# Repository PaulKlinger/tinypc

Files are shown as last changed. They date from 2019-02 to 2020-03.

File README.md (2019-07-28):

# TinyPC / ThinkTiny

This repository contains the code, 3d models, and PCB files for my tiny gaming pc and tiny thinkpad. Both projects use the same code.

| | |
|---| ---|
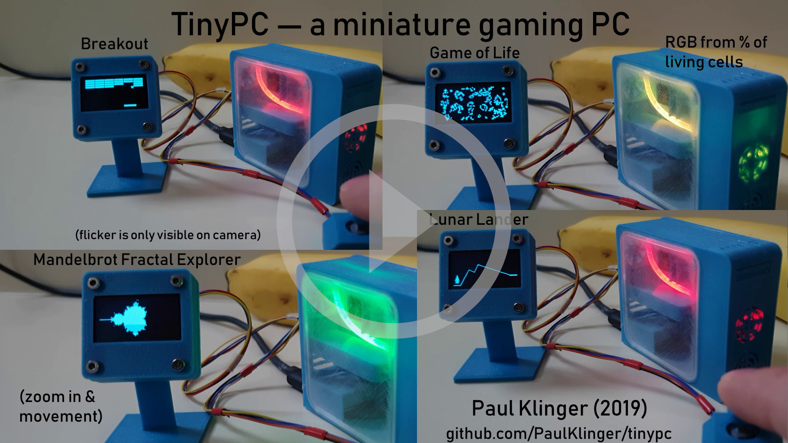
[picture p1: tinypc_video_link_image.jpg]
(https://youtu.be/rgKiFqHrE0A "TinyPC video")
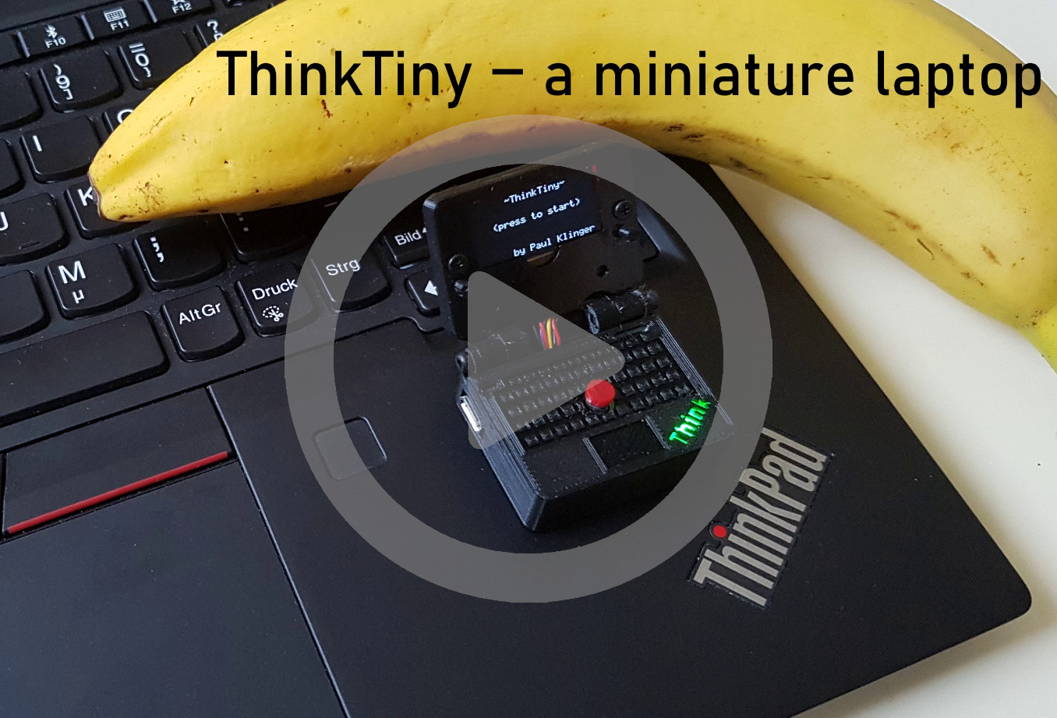
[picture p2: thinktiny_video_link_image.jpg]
(https://youtu.be/0wcxMr_ZupM "ThinkTiny video")
|  |  |

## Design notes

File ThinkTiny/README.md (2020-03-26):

# ThinkTiny — A miniature laptop

(https://youtu.be/0wcxMr_ZupM "Project video")

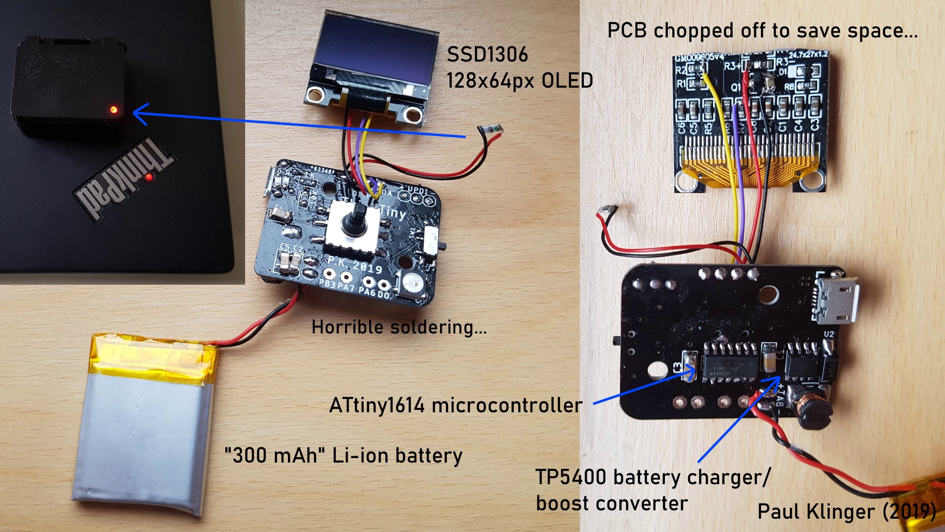
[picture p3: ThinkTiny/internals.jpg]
internals


Components:
- [ATtiny1614 microcontroller](https://octopart.com/attiny1614-ssfr-microchip-82181131)
- [128x64 OLED screen with SSD1306 driver](https://www.aliexpress.com/item/Free-Shipping-White-Blue-Whiteand-Blue-color-0-96-inch-128X64-OLED-Display-Module-For-arduino/32713614136.html)
- [5 way switch](https://www.aliexpress.com/item/32807613480.html)
- [WS2812B LED](https://www.aliexpress.com/item/100pcs-DC5V-WS2812B-4Pins-5050-SMD-with-Built-in-WS2811-IC-Individually-Addressable-Digital-RGB-LED/32542036874.html)
- [2mm PMMA optic fiber](https://www.aliexpress.com/item/5mX-Transparent-side-glow-plastic-PMMA-fiber-optic-cable-solid-core-optic-cable-diameter-2mm-3mm/32807597828.html)
- [power switch](https://www.aliexpress.com/item/32967873133.html)
- [TP5400 charge controller/boost converter](https://www.aliexpress.com/item/32869425291.html)
- [10uH CD54 inductor](https://www.aliexpress.com/item/32956022325.html)
- [Li-ion battery](https://www.aliexpress.com/item/32954488360.html)
- [SS24 diode](https://www.aliexpress.com/item/32904408053.html)
- [10K/6.8K/1K 0805 resistor](https://www.aliexpress.com/item/32880368264.html)
- [5x 47uf 1206 capacitors](https://www.aliexpress.com/item/32373728015.html)
- [2xred 1xgreen 0805 led](https://www.aliexpress.com/item/32816842323.html)
- [Some 30 AWG wire wire](https://www.aliexpress.com/item/30-AWG-Wrapping-Wire-0-25mm-Tin-Plated-Copper-8-Colored-Wire-Wrap-Insulation-Test-Cable/32907507087.html)

I cut off the top of the OLED PCB with flush cutters to make it fit into the case. That's where the pin header sits, so I needed to tap into the connections somewhere else on the PCB. I've marked the points in [this image](black_oled_pin_connection_points.jpg), but be careful, there might be versions of this display with different layout. I also added a capacitor after the voltage regulator on the display board (the three pin component). This gets rid of flickering when there's a lot of white on the screen.

To fit the knob on the 5-way switch the stem needs to be cut off just after the thick section at the top. The knob fits pretty well, but to make sure it doesn't come off I used a drop of superglue to fix it in place. Make sure to turn it upside down while glueing, otherwise the glue runs down into the switch and it stops working...

There's a small piece of fiberoptic in the hole in the display back cover, which transmits and diffuses the light from the red LED. That 0805 LED is directly soldered to an 0805 6.8k resistor and connected back to the main PCB.

The plastic pieces are all printed in PLA with a 0.25mm nozzle and 0.1mm layer height on my [Prusa MK3s](https://shop.prusa3d.com/en/3d-printers/180-original-prusa-i3-mk3-kit.html#). No supports are needed, all the pieces have a flat side to put down on the bed. STL files and the Fusion 360 source file (in case anyone wants to edit them) are in the "3d models" directory. The pcb cover ("pcb cover.stl") is printed with a color change: black filament at the bottom (the top when assembled) and then transparent filament to create the diffuser for the "think" logo and the charging indicator LEDs. I raised the first layer height slightly when printing the pcb cover, so that the keys and "think" font wouldn't get squished together.

The hole on the top right of the pcb cover is used to reprogram the MCU without disassembling everything. I use a small jig with three spring loaded pogo pins ([bought here](https://www.aliexpress.com/item/50pcs-set-New-P75-B1-Dia-1-02mm-100g-Cusp-Spear-Spring-Loaded-Test-Probes-Pogo/32767984398.html)) to connect to three pads (for power, ground, and UPDI data) on the PCB underneath (you need to put some solder in the three holes to make a surface for the pins to push against). The holes are the standard pin header ones, 0.1 inch apart, so you can just solder the pogo pins into three adjacent holes of another protoboard to make a jig. Here's [a picture](https://raw.githubusercontent.com/PaulKlinger/ndice/master/programming_jig.jpg) of the programming jig with a PICkit 4 connected (the PICkit doesn't provide power, so that comes from the usb).

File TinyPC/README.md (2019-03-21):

# TinyPC — A miniature gaming PC

(https://youtu.be/rgKiFqHrE0A "Project video")

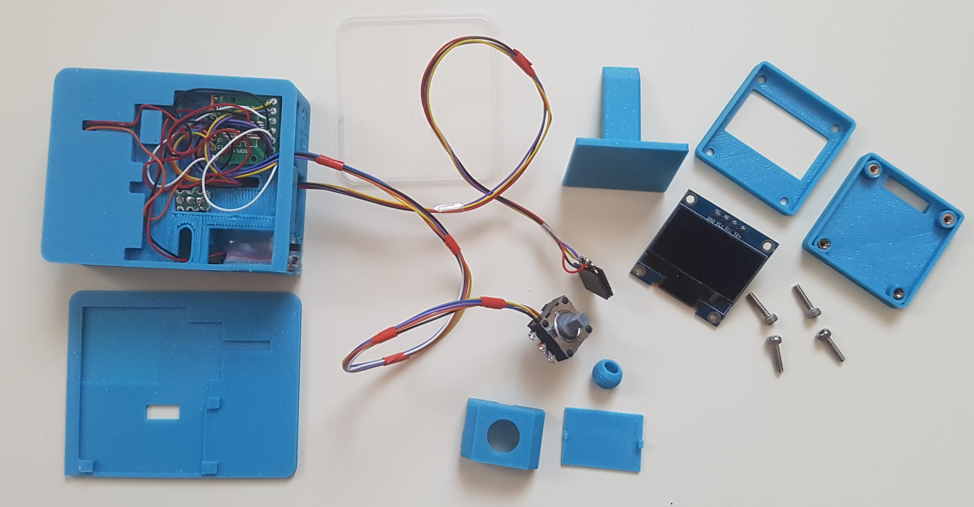
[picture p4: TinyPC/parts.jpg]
parts


Components:
- [ATtiny1614 microcontroller](https://octopart.com/attiny1614-ssfr-microchip-82181131)
- [SOP14 adapter board](https://www.aliexpress.com/item/7kinds-PCB-Board-SOP8-SOP14-SOP16-SOP20-SOP24-SOP28-QFP-FQFP-TQFP-Turn-To-DIP-Adapter/32863813062.html)
- [128x64 OLED screen with SSD1306 driver](https://www.aliexpress.com/item/Free-Shipping-White-Blue-Whiteand-Blue-color-0-96-inch-128X64-OLED-Display-Module-For-arduino/32713614136.html)
- [JS5208 5 way switch](https://octopart.com/js5208-e-switch-7055822?r=sp&s=BNJOYOgrTFqksTVikSivoQ)
- [WS2812B LED](https://www.aliexpress.com/item/100pcs-DC5V-WS2812B-4Pins-5050-SMD-with-Built-in-WS2811-IC-Individually-Addressable-Digital-RGB-LED/32542036874.html)
- [2mm PMMA optic fiber](https://www.aliexpress.com/item/5mX-Transparent-side-glow-plastic-PMMA-fiber-optic-cable-solid-core-optic-cable-diameter-2mm-3mm/32807597828.html)
- micro usb breakout (I used part of a custom PCB from [an earlier project](https://github.com/PaulKlinger/satellite_tracker), you could use [this one](https://www.aliexpress.com/item/10PCS-CJMCU-Breakout-Power-Supply-Module-Micro-USB-Interface-Power-Adapter-Board-USB-5V-Breakout-Module/32815913372.html) for example. Unfortunately all the breakouts I can find use connectors without through hole pins, so they tear out easily.)
- power switch ([this one looks similar to mine](https://www.aliexpress.com/item/Promotion-50-Pcs-SS12D00G3-2-Position-SPDT-1P2T-3-Pin-PCB-Panel-Mini-Vertical-Slide-Switch/32649542037.html))
- [Threaded inserts for the LCD case back](https://www.aliexpress.com/item/100pcs-lot-Brass-insert-M2-M2-5-M3-Through-thread-brass-insert-nut-knurled-nuts/32840519444.html) (These are pretty unnecesary, you can just screw directly into the plastic if you make the hole smaller, or glue the case together. I have a lot of them so I use them for everything. They push into the plastic with a soldering iron set to low heat (~100 °C).)
- [Some 30 AWG wire wire](https://www.aliexpress.com/item/30-AWG-Wrapping-Wire-0-25mm-Tin-Plated-Copper-8-Colored-Wire-Wrap-Insulation-Test-Cable/32907507087.html) to connect everything together.

There's a schematic available [here](schematic/schematic.pdf).

The hole in the side cover (opposite the window) is used to reprogram the MCU without dissasembling the tinypc. I use a small jig with three spring loaded pogo pins ([bought here](https://www.aliexpress.com/item/50pcs-set-New-P75-B1-Dia-1-02mm-100g-Cusp-Spear-Spring-Loaded-Test-Probes-Pogo/32767984398.html)) to connect to three pads (for power, ground, and UPDI data) in a piece of protoboard underneath (you need to put some solder in the three holes to make a surface for the pins to push against). The holes are the standard pin header ones, 0.1 inch apart, so you can just solder the pogo pins into three adjacent holes of another protoboard to make a jig. Here's [a picture](https://raw.githubusercontent.com/PaulKlinger/ndice/master/programming_jig.jpg) of the programming jig with a PICkit 4 connected (the PICkit doesn't provide power, so that comes from the usb). (I don't really recommend the pickit, the AVR support is still in beta and there are some irritating bugs.)

The window is printed using transparent PLA filament. To get it even this transparent I had to polish it a lot, using abrasive paper from 200 to 5000 grit and acrylic polishing compound.

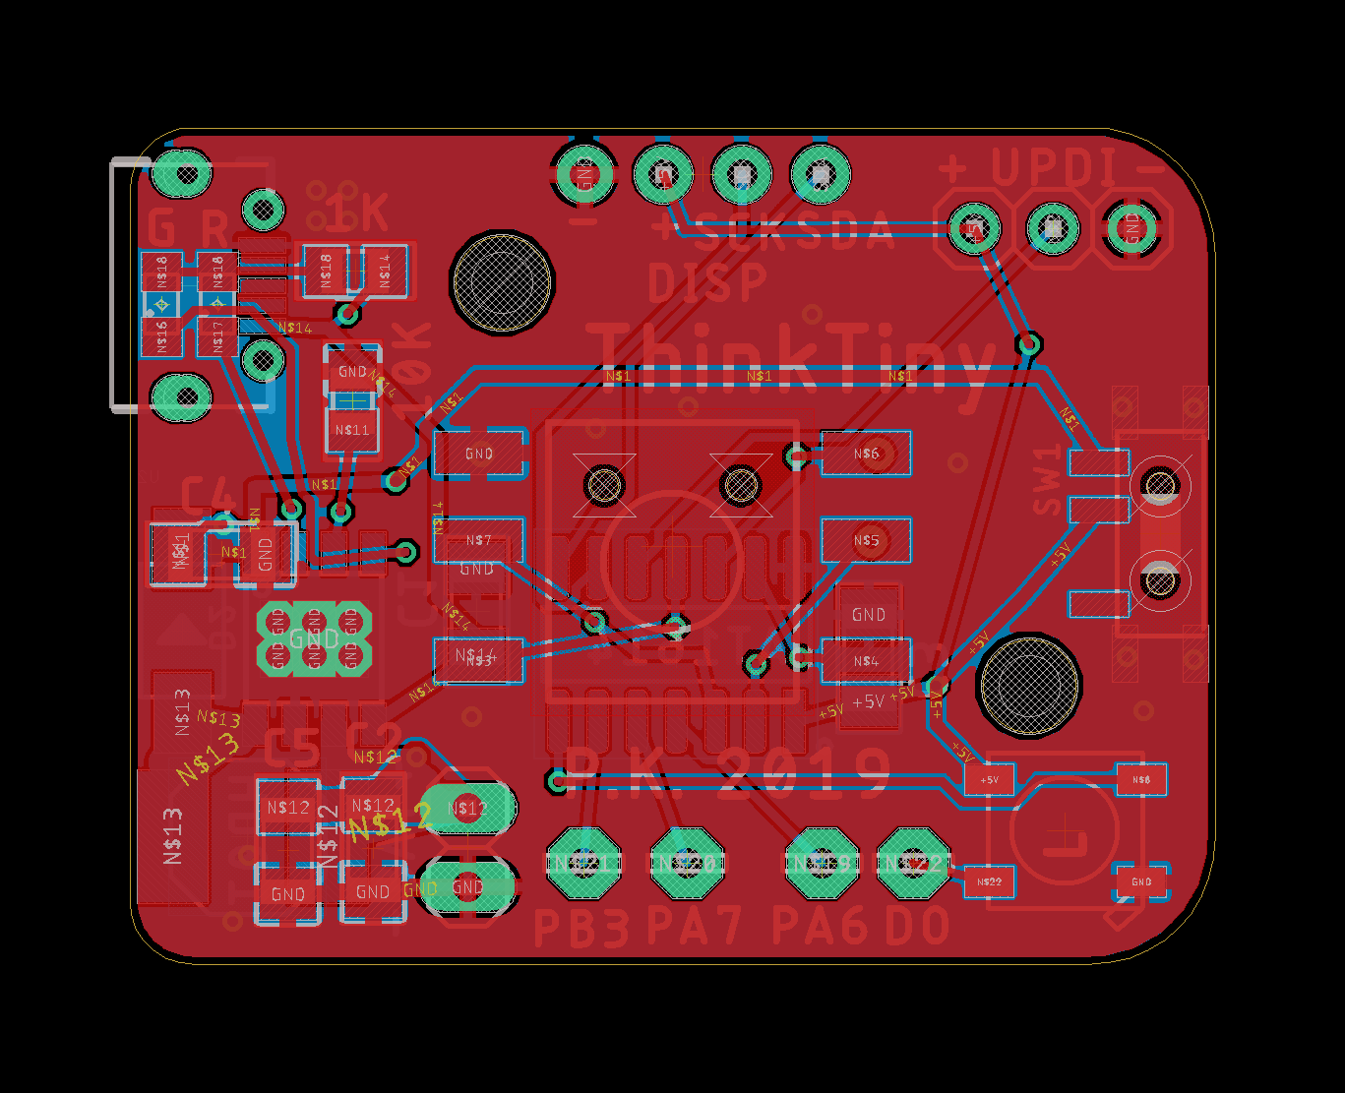
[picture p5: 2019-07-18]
ThinkTiny/pcb/pcb.png

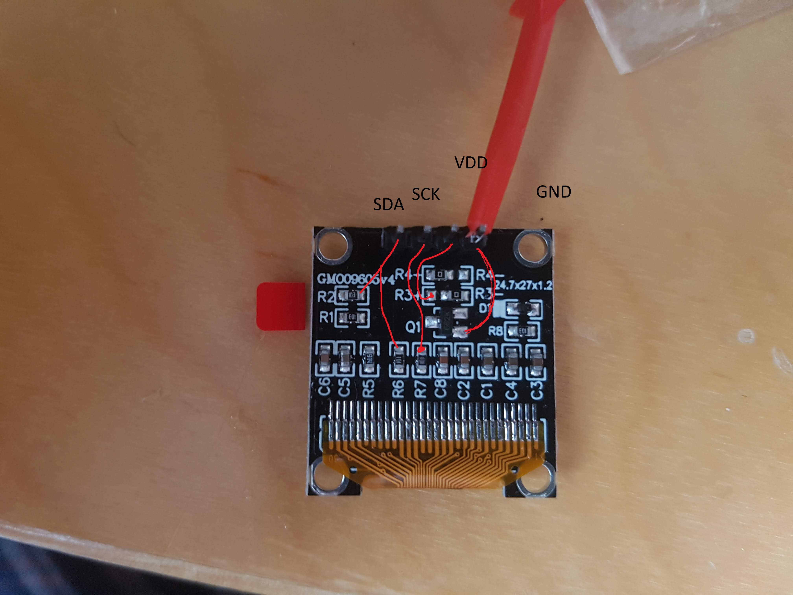
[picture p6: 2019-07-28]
ThinkTiny/black_oled_pin_connection_points.jpg

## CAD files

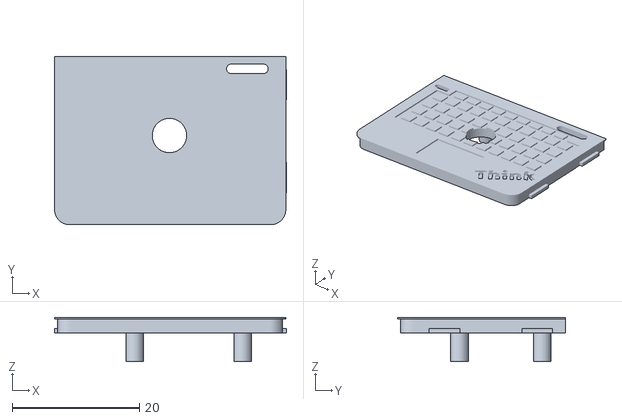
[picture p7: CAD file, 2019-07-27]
ThinkTiny/3d models/pcb cover.stl
36.5 x 26.5 x 7.00

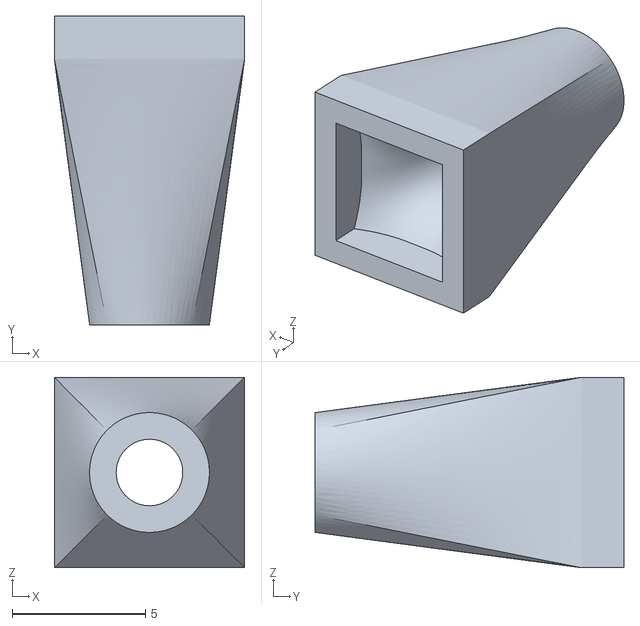
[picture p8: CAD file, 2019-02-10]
TinyPC/3d models/fiber_coupling.stl
7.15 x 11.6 x 7.15

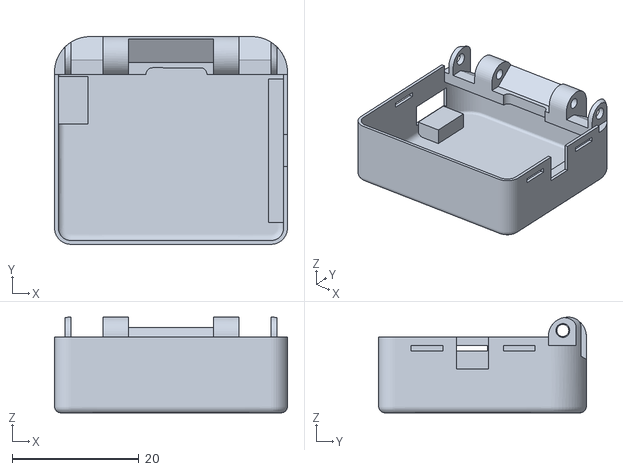
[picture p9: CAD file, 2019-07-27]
ThinkTiny/3d models/case bottom.stl
36.8 x 32.8 x 15.1

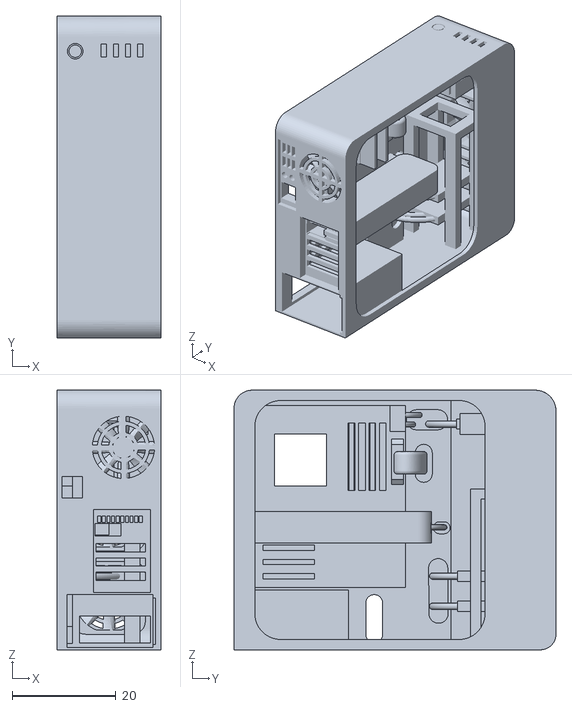
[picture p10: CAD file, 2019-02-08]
TinyPC/3d models/functional_pc_model v1.stl
20.0 x 62.0 x 50.0

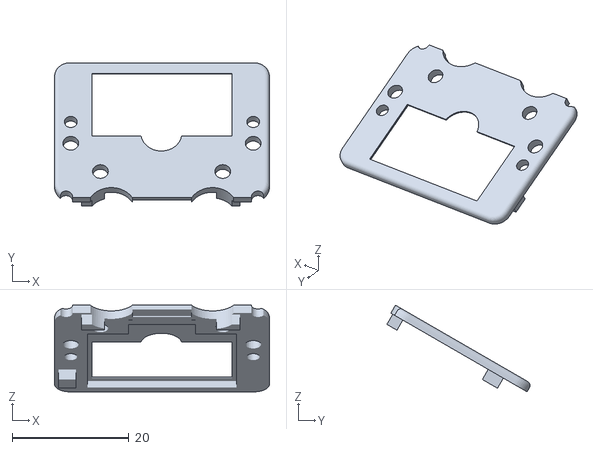
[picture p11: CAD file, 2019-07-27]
ThinkTiny/3d models/display_case_front.stl
36.8 x 24.5 x 14.8

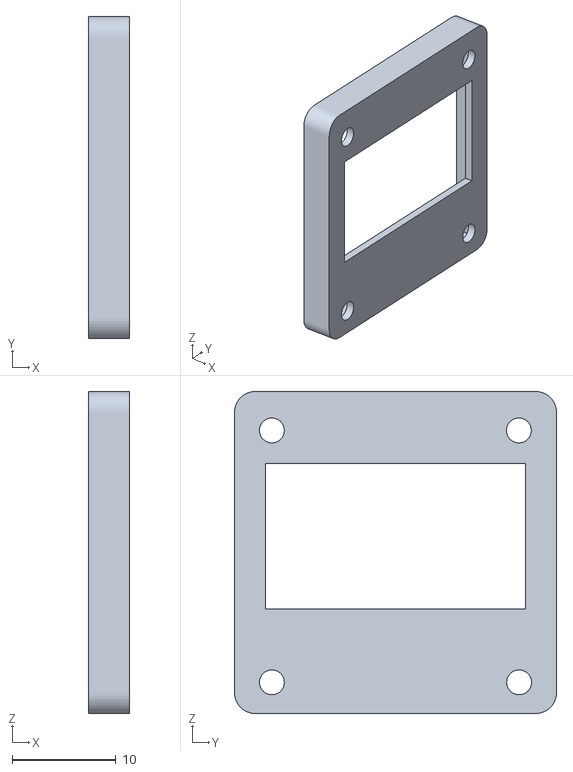
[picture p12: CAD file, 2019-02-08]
TinyPC/3d models/monitor_front.stl
3.90 x 31.0 x 31.0

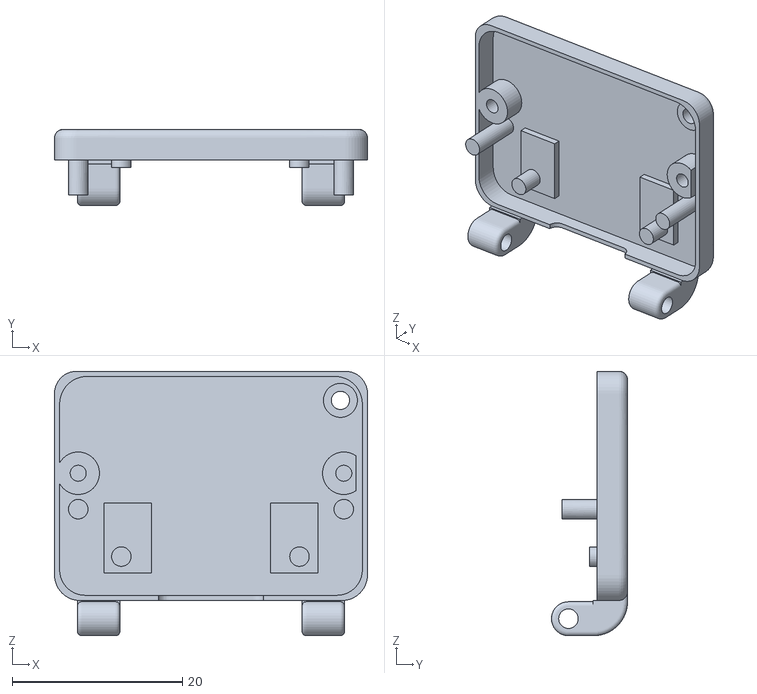
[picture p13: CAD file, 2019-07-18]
ThinkTiny/3d models/display_case_back.stl
36.8 x 8.95 x 31.1

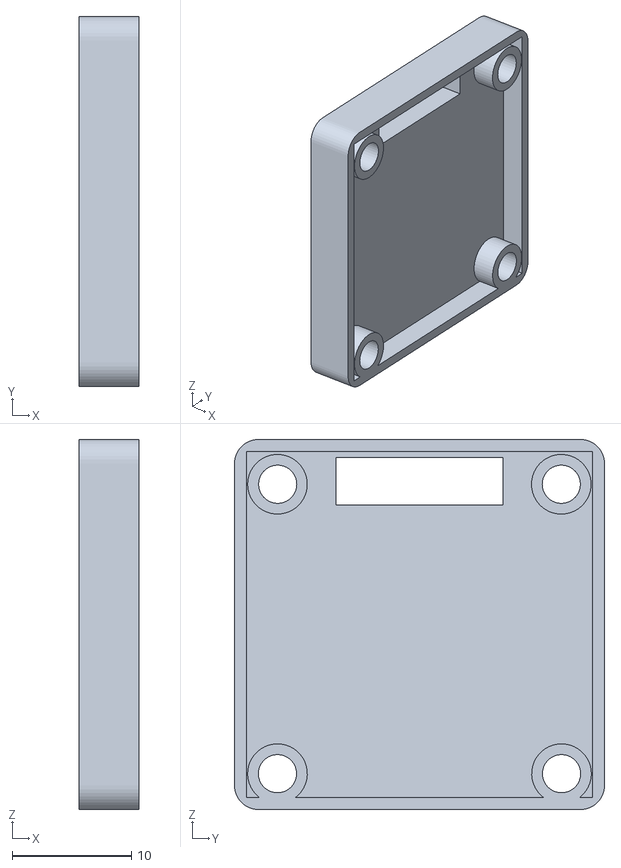
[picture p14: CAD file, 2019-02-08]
TinyPC/3d models/monitor_rear.stl
5.00 x 31.0 x 31.0

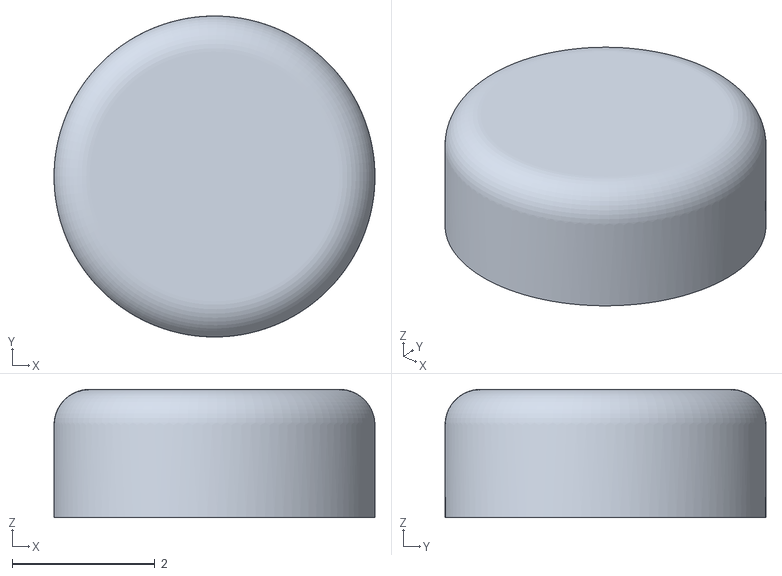
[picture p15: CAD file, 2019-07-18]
ThinkTiny/3d models/knob.stl
4.50 x 4.50 x 1.80

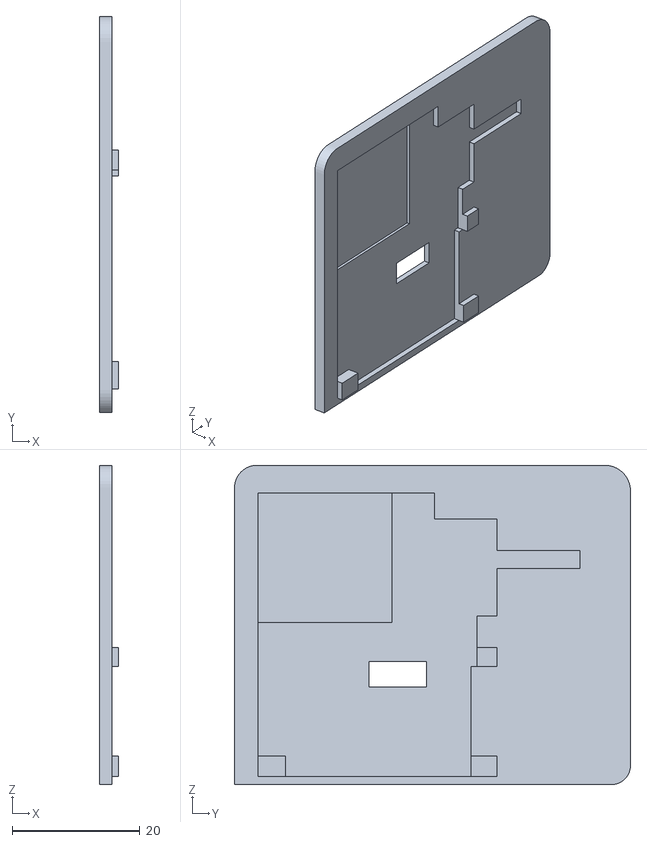
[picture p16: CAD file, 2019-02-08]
TinyPC/3d models/side_cover.stl
3.00 x 62.0 x 50.0

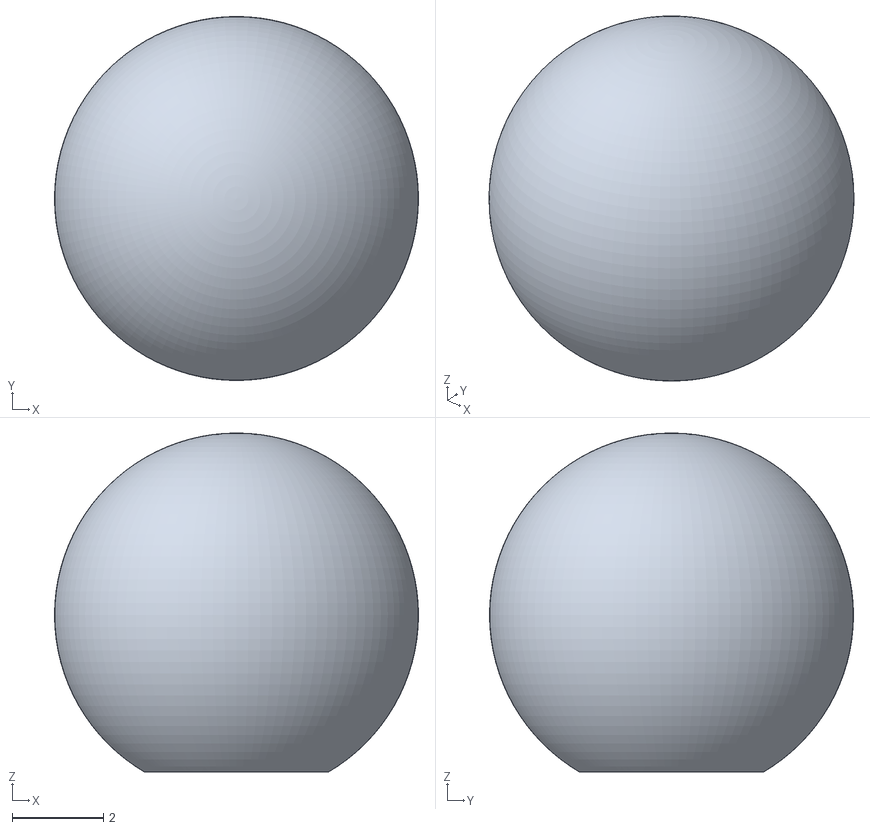
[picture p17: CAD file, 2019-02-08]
TinyPC/3d models/ball.stl
8.00 x 8.00 x 7.45

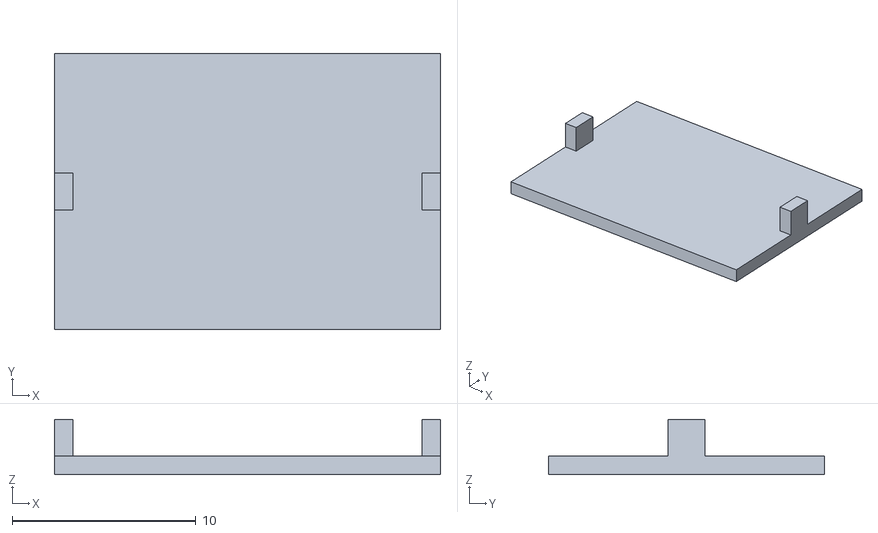
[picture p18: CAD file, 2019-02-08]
TinyPC/3d models/joystick bottom.stl
21.0 x 15.0 x 3.00

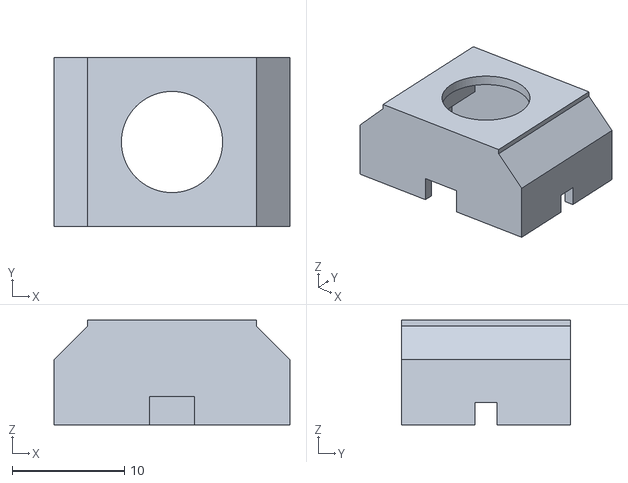
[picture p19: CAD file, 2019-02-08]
TinyPC/3d models/joystick top.stl
21.0 x 15.0 x 9.30

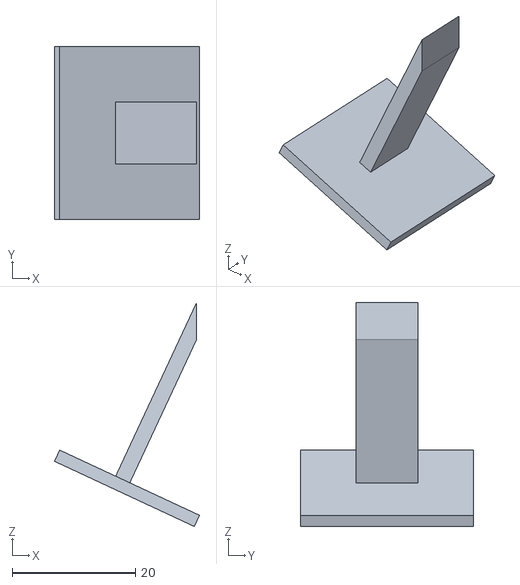
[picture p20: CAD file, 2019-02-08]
TinyPC/3d models/monitor_stand.stl
23.5 x 28.0 x 36.3

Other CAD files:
ThinkTiny/3d models/tiny_thinkpad.f3d
TinyPC/3d models/tinypc.f3d

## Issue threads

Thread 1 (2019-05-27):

Problem with code not working outside of this project

sognatore99, 2019-05-27:
Paul I was able to get your code working using your provided project files. However I am having an issue trying to use the I2C code outside of your code.  I am using Atmel Studio vice MPLAB X (which is what I used to get your code to work).  I have create a project that only needs the LCD and I2C code.  I have attached if you don't mind looking it over.  I seem to be missing something very basic.  How does the project know to use PB0 and PB1 for the SDA and SDL lines?  When I step through the code it appears to be working.  Also I made sure that F_CPU 20000000 was set.  If you have the time I would appreciate a quick look.  I will continue to try to figure it out in the mean time.  Thanks in advance.

[OnlyI2C.zip](https://github.com/PaulKlinger/tinypc/files/3222072/OnlyI2C.zip)

PaulKlinger, 2019-05-27:
I took a quick look at your project and I can't see anything obviously wrong in the code. Maybe there's some issue with the fuse configuration? I haven't used AtmelStudio yet, so I'm not sure how this works there. In the MPLAB X project the fuses are set in [device_config.c](https://github.com/PaulKlinger/tinypc/blob/master/code/mcc_generated_files/device_config.c)

The I2C peripheral (TWI0) uses PB0 and PB1 by default. Using the PORTMUX registers it's supposed to be possible to switch it to using PA1 & PA2, but that option seems to be missing from the datasheet.

sognatore99, 2019-05-27:
Thanks for looking, I will look into the fuse configuration.  The I2C stuff is very frustrating, I switched from MPLAB to Atmel since I am more comfortable, but my expertise is not in C/C++.  Also thanks for uploading your great project it was a pleasure to look into!

sognatore99, 2019-05-27:
So a follow up, I got it working.  I guess in my haste at 3:00am when I was attempting to create a "simple_i2c_fgras78.h" file I must have copied and pasted code to the simple_i2c_fgras78.c file something like this "void TWI_init();uint8_t TWI_start(uint8_t deviceAddr)" the compiler did not complain!  I am a C# guy so this stuff always kicks me where it hurts!  Again thanks for a great post and taking a look at my code.

PaulKlinger, 2019-05-27:
Great! It's always nice to know that my projects are useful for someone :)

That was a weird problem though, I actually saw that and tried compiling this:

```
#include <stdio.h>
void test2() {
        printf("\ntest2\n");
}
void test2();int main() {
        printf("test");
        test2();
}
```

and it worked normally; sorry I didn't mention it. Maybe it has something to do with the function also being declared in the header file (I don't really know much about C either).

Closed 2019-05-27.

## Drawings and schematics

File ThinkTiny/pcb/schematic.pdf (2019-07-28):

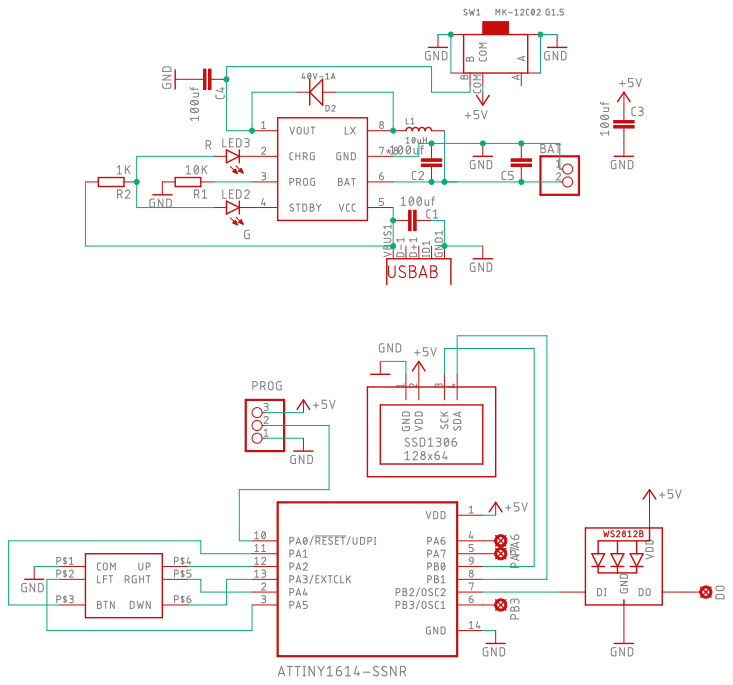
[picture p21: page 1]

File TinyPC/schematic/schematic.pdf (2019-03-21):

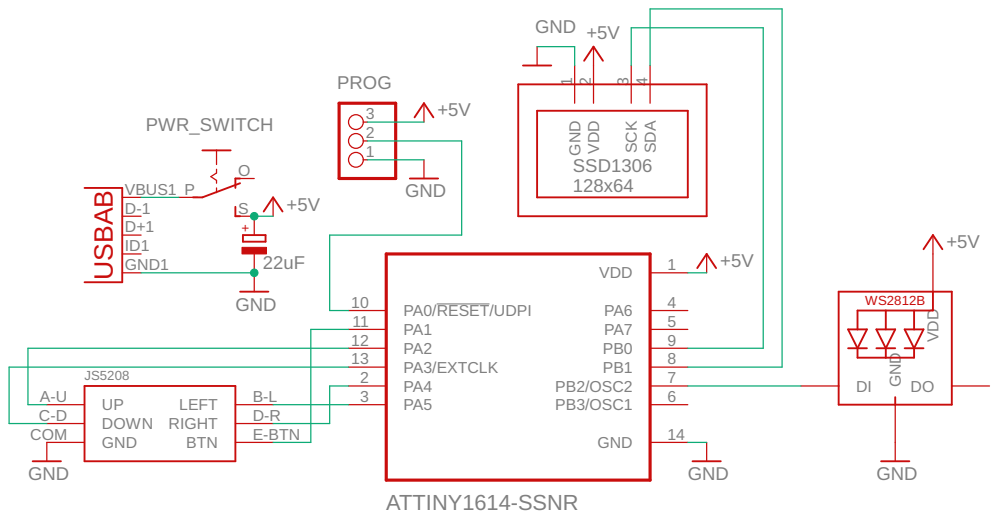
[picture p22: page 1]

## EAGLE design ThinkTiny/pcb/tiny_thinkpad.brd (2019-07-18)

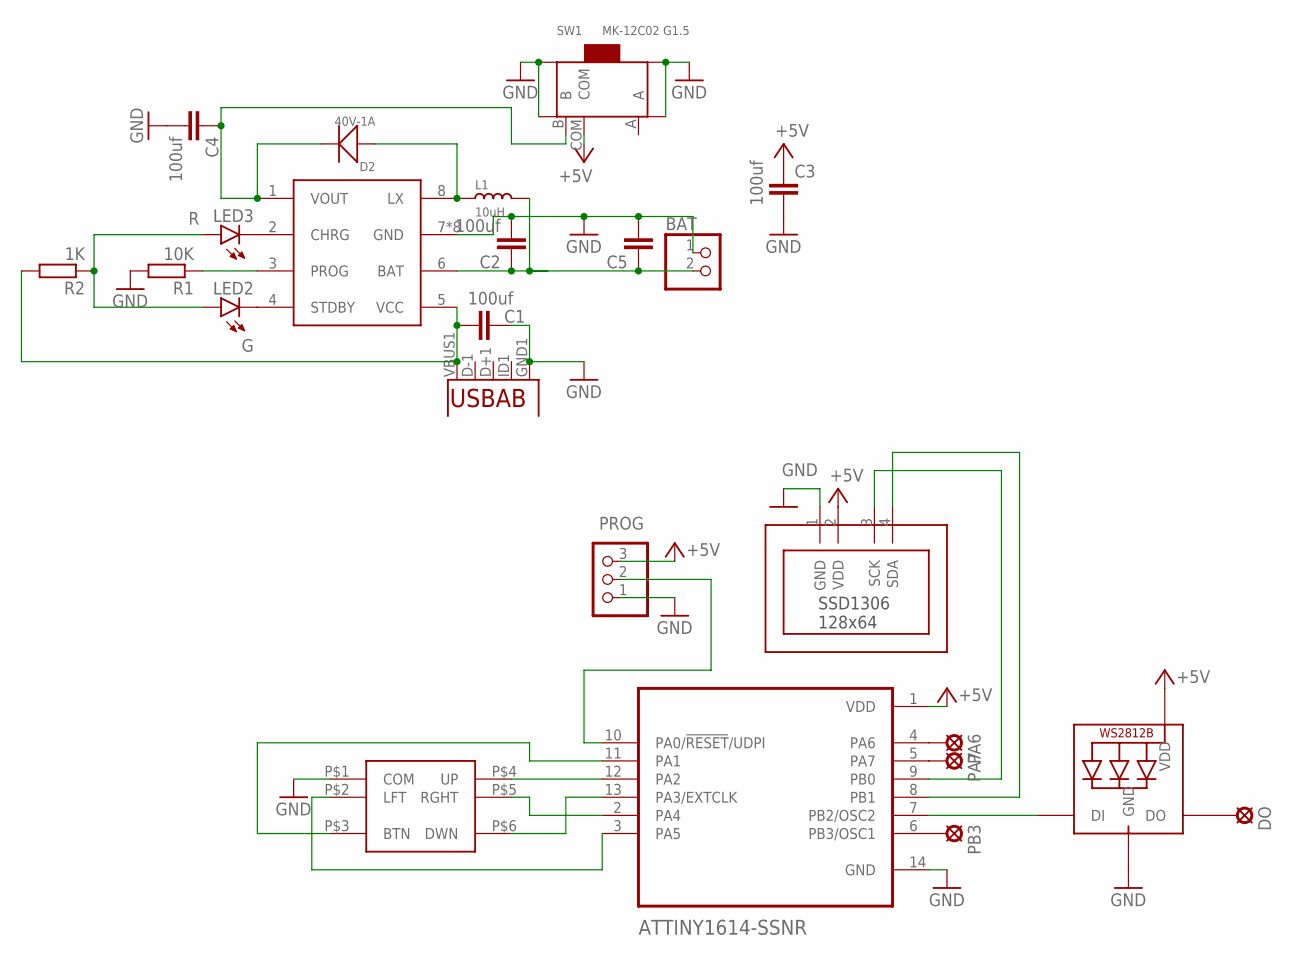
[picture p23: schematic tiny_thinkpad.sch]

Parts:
AT1614: ATTINY1614-SSNR; SOIC127P600X175-14N
BAT: PINHD-1X2; 1X02
C1, C2, C3, C4, C5: 100uf; C1206
D2: 40V-1A; DO-214AC
DISP: SSD1306_128X64_OLEDPINHEAD; 1X04-CLEANBIG
DO: LSP10
L1: 10uH; L5040S
LED1: WS2812B5050; WS2812B
LED2: G; SML0805
LED3: R; SML0805
PA6, PA7: LSP10
PB3: LSP10
PROG: PINHD-1X3; 1X03
R1: 10K; R0805
R2: 1K; R0805
SW1: MK-12C02 G1.5; SW7-SMD-L6.7X2.7X3.2MM
U2: USB-THROUGH; USB-MICRO-THROUGH
U$3: TP5400; SOP-8
U$4: 5WAY_SMD_SWITCH; SUNROM_5WAY_SMD_SWITCH

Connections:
+5V: AT1614.1 (VDD), C3.1, DISP.2 (VDD), LED1.1-VDD (VDD), PROG.3, SW1.COM
GND: AT1614.14 (GND), BAT.1, C1.1, C2.2, C3.2, C4.2, C5.2, DISP.1 (GND), LED1.3-GND (GND), PROG.1, R1.2, SW1.SS1, SW1.SS2, SW1.SS3, SW1.SS4, U2.GND1 (GND), U$3.7 (GND), U$3.BOTTOM (GND), U$3.P$1 (GND), U$3.P$2 (GND), U$3.P$3 (GND), U$3.P$4 (GND), U$3.P$5 (GND), U$3.P$6 (GND), U$4.P$1 (COM)
unnamed: C4.1, D2.2 (-), SW1.B, U$3.1 (VOUT)
unnamed: AT1614.10 (PA0/!RESET!/UDPI), PROG.2
unnamed: AT1614.11 (PA1), U$4.P$3 (BTN)
unnamed: AT1614.13 (PA3/EXTCLK), U$4.P$6 (DWN)
unnamed: AT1614.2 (PA4), U$4.P$5 (RGHT)
unnamed: AT1614.12 (PA2), U$4.P$4 (UP)
unnamed: AT1614.3 (PA5), U$4.P$2 (LFT)
unnamed: AT1614.7 (PB2/OSC2), LED1.4-DIN (DI)
unnamed: R1.1, U$3.3 (PROG)
unnamed: BAT.2, C2.1, C5.1, L1.2, U$3.6 (BAT)
unnamed: D2.1 (+), L1.1, U$3.8 (LX)
unnamed: C1.2, R2.2, U2.VBUS1 (VBUS), U$3.5 (VCC)
unnamed: LED2.C, U$3.4 (STDBY)
unnamed: LED3.C, U$3.2 (CHRG)
unnamed: LED2.A, LED3.A, R2.1
unnamed: AT1614.4 (PA6), PA6.MP
unnamed: AT1614.5 (PA7), PA7.MP
unnamed: AT1614.6 (PB3/OSC1), PB3.MP
unnamed: DO.MP, LED1.2-DOUT (DO)
SCK: AT1614.9 (PB0), DISP.3 (SCK)
SDA: AT1614.8 (PB1), DISP.4 (SDA)

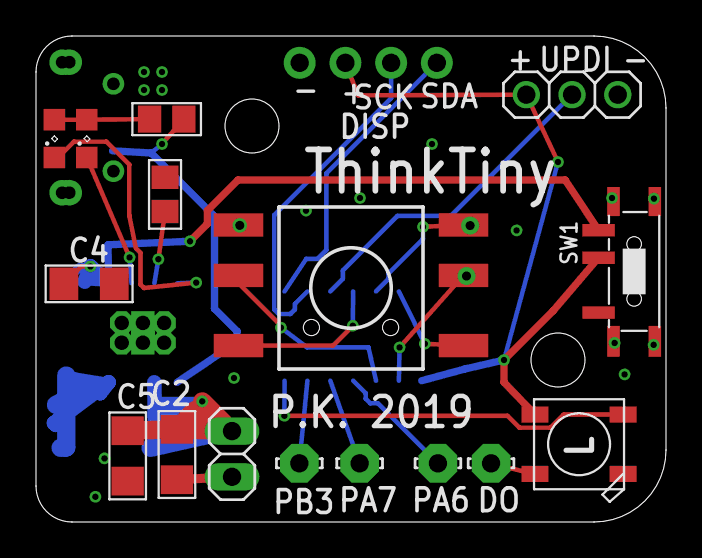
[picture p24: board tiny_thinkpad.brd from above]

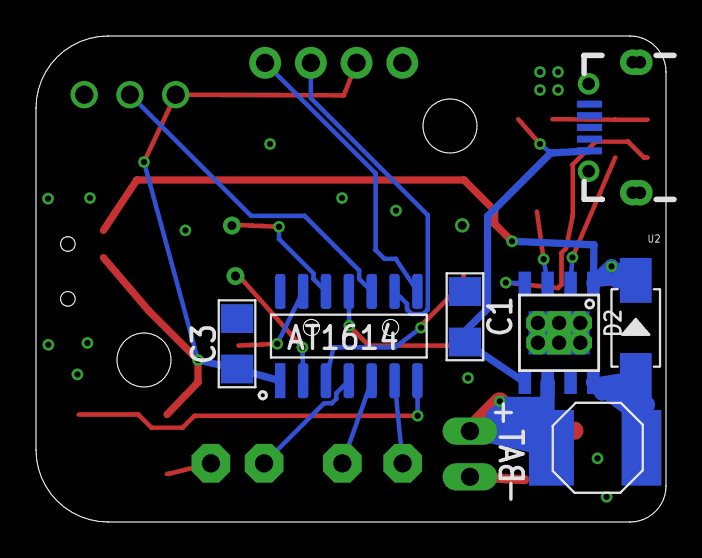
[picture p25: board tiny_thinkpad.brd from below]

Board: 2 copper layers, 35.0 x 27.0 mm, 24 parts (7 on the bottom side), 23 nets.

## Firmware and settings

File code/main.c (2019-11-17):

/*
 * File:   main.c
 * Author: Paul
 *
 * Created on January 11, 2019, 7:35 PM
 */


#include "mcc_generated_files/config/clock_config.h"
#include "mcc_generated_files/mcc.h"


#include <avr/io.h>
#include <util/delay.h>

#include "config.h"

#include "lcd.h"

#include "utilities.h"
#include "strings.h"
#include "applications/snake.h"
#include "applications/gol.h"
#include "applications/breakout.h"
#include "applications/lander.h"
#include "applications/mandelbrot.h"
#include "applications/tetris.h"
#include "applications/mines.h"


void show_launch_screen() {
#ifdef THINKTINY
    set_led(255,0,0);
#else
    set_led(0,255,0);
#endif
    lcd_goto_xpix_y(TITLE_OFFSET,0);
    lcd_puts_p(string_title);
    lcd_gotoxy(3,3);
    lcd_puts("(press to start)");
    lcd_gotoxy(6,7);
    lcd_puts("by Paul Klinger");
    lcd_display();
    wait_for_button();
}

typedef struct MenuEntry {
    const char *name;
    void (*start_function)();
} MenuEntry;

typedef struct {
    uint8_t selected_index;
    uint8_t length;
    MenuEntry entries[8];
} Menu;



void display_menu(Menu *menu) {
    lcd_clear_buffer();
    lcd_goto_xpix_y(TITLE_OFFSET,0);
    lcd_puts_p(string_title);
    for (uint8_t i=0; i < menu->length; i++) {
        lcd_gotoxy(0,i + 1);
        if (i == menu->selected_index) {
            lcd_puts("> ");
        }
        lcd_gotoxy(2,i + 1);
        lcd_puts(menu->entries[i].name);
    }
    lcd_display();
}

void show_menu() {
    Menu menu = {
        .length=6, .selected_index=0,
        .entries={
            {"Snake", &run_snake},
            //{"Breakout", &run_breakout},
            {"Tetris", &run_tetris},
            {"Lander", &run_lander},
            {"Mines", &run_mines},
            {"Game of Life", &run_gol},
            {"Mandelbrot", &run_mandelbrot}
        }
    };
    display_menu(&menu);
    bool wait_for_release = true;
    while (1) {
        if (!joystick_pressed && !button_pressed) {
            wait_for_release = false;
        }
        if (joystick_pressed && !wait_for_release) {
            wait_for_release = true;
            if (last_joystick_direction == UP){
                menu.selected_index = (menu.selected_index + menu.length - 1) % menu.length;
            } else if (last_joystick_direction == DOWN) {
                menu.selected_index++;
                menu.selected_index %= menu.length;
            }
            display_menu(&menu);
        } else if (button_pressed && !wait_for_release){
            menu.entries[menu.selected_index].start_function();
            wait_for_release = true;
            display_menu(&menu);
        }
    };
    
}

int main(void) {
    SYSTEM_Initialize();
    _delay_ms(100); // make sure LCD power is stable before init
    lcd_init(LCD_DISP_ON);
    show_launch_screen();
    srand((unsigned int) RTC.CNT);
    show_menu();
}

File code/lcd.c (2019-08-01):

/*
 * This file is part of lcd library for ssd1306/sh1106 oled-display.
 *
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
 * Diese Datei ist Teil von lcd library for ssd1306/sh1106 oled-display.
 *
 * lcd library for ssd1306/sh1106 oled-display ist Freie Software: Sie können es unter den Bedingungen
 * der GNU General Public License, wie von der Free Software Foundation,
 * Version 3 der Lizenz oder jeder späteren
 * veröffentlichten Version, weiterverbreiten und/oder modifizieren.
 *
 * lcd library for ssd1306/sh1106 oled-display wird in der Hoffnung, dass es nützlich sein wird, aber
 * OHNE JEDE GEWÄHRLEISTUNG, bereitgestellt; sogar ohne die implizite
 * Gewährleistung der MARKTFÄHIGKEIT oder EIGNUNG FÜR EINEN BESTIMMTEN ZWECK.
 * Siehe die GNU General Public License für weitere Details.
 *
 * Sie sollten eine Kopie der GNU General Public License zusammen mit diesem
 * Programm erhalten haben. Wenn nicht, siehe <http://www.gnu.org/licenses/>.
 *
 *  lcd.h
 *
 *  Created by Michael Köhler on 22.12.16.
 *  Copyright 2016 Skie-Systems. All rights reserved.
 *
 * 
 *  lib for OLED-Display with ssd1306/sh1106-Controller
 *  first dev-version only for I2C-Connection
 *  at ATMega328P like Arduino Uno
 *
 *  at GRAPHICMODE lib needs static SRAM for display:
 *  DISPLAY-WIDTH * DISPLAY-HEIGHT + 2 bytes
 *
 *  at TEXTMODE lib need static SRAM for display:
 *  2 bytes (cursorPosition)
 */

#include "lcd.h"
#include "font.h"
#include <string.h>
//#include "mcc_generated_files/include/i2c_simple_master.h"
#include "simple_i2c_fgras78.c"

static struct {
    uint8_t x;
    uint8_t y;
} cursorPosition;
#if defined GRAPHICMODE
#include <stdlib.h>
uint8_t displayBuffer[DISPLAY_HEIGHT/8][DISPLAY_WIDTH];
#elif defined TEXTMODE
#else
#error "No valid displaymode! Refer lcd.h"
#endif


const uint8_t init_sequence [] PROGMEM = {    // Initialization Sequence
    LCD_DISP_OFF,    // Display OFF (sleep mode)
    0x20, 0b00,        // Set Memory Addressing Mode
    // 00=Horizontal Addressing Mode; 01=Vertical Addressing Mode;
    // 10=Page Addressing Mode (RESET); 11=Invalid
    0xB0,            // Set Page Start Address for Page Addressing Mode, 0-7
    0xC8,            // Set COM Output Scan Direction
    0x00,            // --set low column address
    0x10,            // --set high column address
    0x40,            // --set start line address
    0x81, 0x3F,        // Set contrast control register
    0xA1,            // Set Segment Re-map. A0=address mapped; A1=address 127 mapped.
    0xA6,            // Set display mode. A6=Normal; A7=Inverse
    0xA8, 0x3F,        // Set multiplex ratio(1 to 64)
    0xA4,            // Output RAM to Display
    // 0xA4=Output follows RAM content; 0xA5,Output ignores RAM content
    0xD3, 0x00,        // Set display offset. 00 = no offset
    0xD5,            // --set display clock divide ratio/oscillator frequency
    0xF0,            // --set divide ratio
    0xD9, 0x22,        // Set pre-charge period
    0xDA, 0x12,        // Set com pins hardware configuration
    0xDB,            // --set vcomh
    0x20,            // 0x20,0.77xVcc
    0x8D, 0x14,        // Set DC-DC enable
    
    
};

void i2c_byte(uint8_t byte_to_send) {
    TWI_WRITE(byte_to_send);
}

#pragma mark LCD COMMUNICATION
void lcd_command(uint8_t cmd[], uint8_t size) {
    TWI_start(LCD_I2C_ADR);
    i2c_byte(0x00);    // 0x00 for command, 0x40 for data
    for (uint8_t i=0; i<size; i++) {
        i2c_byte(cmd[i]);
    }
    TWI_STOP();
}
void lcd_data(uint8_t data[], uint16_t size) {
    TWI_start(LCD_I2C_ADR);
    i2c_byte(0x40);    // 0x00 for command, 0x40 for data
    for (uint16_t i = 0; i<size; i++) {
        i2c_byte(data[i]);
    }
    TWI_STOP();
}
#pragma mark -
#pragma mark GENERAL FUNCTIONS
void lcd_init(uint8_t dispAttr){
    TWI_init();
    uint8_t commandSequence[sizeof(init_sequence)+1];
    for (uint8_t i = 0; i < sizeof (init_sequence); i++) {
        commandSequence[i] = (pgm_read_byte(&init_sequence[i]));
    }
    commandSequence[sizeof(init_sequence)]=(dispAttr);
    lcd_command(commandSequence, sizeof(commandSequence));
    lcd_clrscr();
}
void lcd_gotoxy(uint8_t x, uint8_t y){
    x = x * sizeof(FONT[0]);
    lcd_goto_xpix_y(x, y);
}

void lcd_goto_xpix_y(uint8_t x, uint8_t y){
    if( x > (DISPLAY_WIDTH) || y > (DISPLAY_HEIGHT/8-1)) return;// out of display
    cursorPosition.x=x;
    cursorPosition.y=y;
#if defined SSD1306
#if defined BLACKBOARD
    // The black board uses a different controller which actually follows
    // the SSD1306 datasheet: The commands 0xb0 to 0xb7 are not valid in
    // horizontal addressing mode.
    // So we have to use the longer 0x22 command instead.
    uint8_t commandSequence[] = {0x22, y, 0x07, 0x21, x, 0x7f};
#else
    uint8_t commandSequence[] = {0xb0+y, 0x21, x, 0x7f};
#endif
#elif defined SH1106
    uint8_t commandSequence[] = {0xb0+y, 0x21, 0x00+((2+x) & (0x0f)), 0x10+( ((2+x) & (0xf0)) >> 4 ), 0x7f};
#endif
    lcd_command(commandSequence, sizeof(commandSequence));
}

void lcd_clrscr(void){
#ifdef GRAPHICMODE
    lcd_clear_buffer();
    lcd_display();
#elif defined TEXTMODE
    uint8_t displayBuffer[DISPLAY_WIDTH];
    memset(displayBuffer, 0x00, sizeof(displayBuffer));
    for (uint8_t i = 0; i < DISPLAY_HEIGHT/8; i++){
        lcd_gotoxy(0,i);
        lcd_data(displayBuffer, sizeof(displayBuffer));
    }
#endif
    lcd_home();
}
void lcd_home(void){
    lcd_gotoxy(0, 0);
}
void lcd_invert(uint8_t invert){
    //i2c_start((LCD_I2C_ADR << 1) | 0);
    TWI_start(LCD_I2C_ADR);
    uint8_t commandSequence[1];
    if (invert != YES) {
        commandSequence[0] = 0xA6;
    } else {
        commandSequence[0] = 0xA7;
    }
    lcd_command(commandSequence, 1);
    TWI_STOP();
}
void lcd_sleep(uint8_t sleep){
    //i2c_start((LCD_I2C_ADR << 1) | 0);
    TWI_start(LCD_I2C_ADR);
    uint8_t commandSequence[1];
    if (sleep != YES) {
        commandSequence[0] = 0xAF;
    } else {
        commandSequence[0] = 0xAE;
    }
    lcd_command(commandSequence, 1);
    TWI_STOP();
}
void lcd_set_contrast(uint8_t contrast){
    uint8_t commandSequence[2] = {0x81, contrast};
    lcd_command(commandSequence, sizeof(commandSequence));
}
void lcd_putc(char c){
            // mapping char
            c -= ' ';
        for (uint8_t i = 0; i < sizeof(FONT[0]); i++)
        {
            // load bit-pattern from flash
            displayBuffer[cursorPosition.y][cursorPosition.x+i] =pgm_read_byte(&(FONT[(uint8_t)c][i]));
        }
        cursorPosition.x += sizeof(FONT[0]);
}

void lcd_puts(const char* s){
    while (*s) {
        lcd_putc(*s++);
    }
}
void lcd_puts_p(const char* progmem_s){
    register uint8_t c;
    while ((c = pgm_read_byte(progmem_s++))) {
        lcd_putc(c);
    }
}
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

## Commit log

2019-02-08 inital commit, stl files
    [ball.stl, functional_pc_model v1.stl, joystick bottom.stl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]
2019-02-08 added fusion 360 design file
    [tinypc.f3d]
2019-02-09 added note about window printing
2019-02-09 added threaded inserts to parts list
2019-02-10 added fiber coupling .stl file
    [fiber_coupling.stl]
2019-02-10 use interrupts to catch fast joystick movements
2019-02-10 initialize joystick direction on reset
    [main.c]
2019-02-12 started work on breakout
    currently bouncing ball and static blocks, next todo is collision with blocks
2019-02-13 correctly truncate display_block region
    [lcd.c]
2019-02-13 final(ish) breakout, multiple stages
2019-02-15 set I2C baudrate to 800kHz
    I'm sure I did this before??
2019-02-15 started work on lunar lander game
    Mostly working, just conditions for successful landing and scoring stuff missing. But progmem is at 99% so, need to work on that first.
    [main.c]
2019-02-16 complete lander game, "procedural" terrain, multiple stages
2019-02-16 highlight landing pad, tweaked collision
2019-03-21 added schematic
    [schematic.sch]
2019-07-12 made compatible with black pcb version of OLED
2019-07-15 added led dim factor (for laptop)
2019-07-18 added ThinkTiny, reorganized
    [ball.stl, case bottom.stl, display_case_back.stl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]
2019-07-18 lander: don't abort stage when pressing button
2019-07-19 simplified button handling
2019-07-27 set led color from points for tetris
2019-07-27 updated 3d models
    [case bottom.stl, display_case_front.stl, pcb cover.stl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]
2019-07-28 added gerbers and schematic pdf
    [tiny_thinkpad.GBL, tiny_thinkpad.GBO, tiny_thinkpad.GBP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]
2019-07-28 some assembly tips added
2019-07-28 some more assembly tips
2019-07-29 added some info about 3d prints
2019-07-31 more 3d print details
2019-08-16 changed default led color to red for thinktiny
2019-11-17 added delay before display init, removed unused file
    On one of the ThinkTinys the display would only work after turning it
    on-off-on. Adding a small delay before makes it work consistently,
    probably because the voltage has time to stabilise.
    Removed unused/empty autogenerated slpcontrol file to get the
    required space. There's some more potential to save space there.
    [main.c]

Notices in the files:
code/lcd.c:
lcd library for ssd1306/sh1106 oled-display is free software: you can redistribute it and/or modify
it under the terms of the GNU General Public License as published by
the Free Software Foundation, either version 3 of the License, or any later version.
